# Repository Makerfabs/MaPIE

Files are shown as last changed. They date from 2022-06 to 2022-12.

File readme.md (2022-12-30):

# Makerfabs MaPIE

```c++
/*
Version:		V2.1
Author:			Vincent
Create Date:	2022/6/2
Note:

2022/12/30		V2.1 Edit wiki link
2022/11/23		V2.0 Add MaPIE 0.96 OLED
2022/6/2		V1.0 Create Project
			
*/
```

[toc]

# Makerfabs

[Makerfabs home page](https://www.makerfabs.com/)

[Makerfabs Wiki](https://wiki.makerfabs.com/)

# What is MaPIE 

MaPIE is Makerfabs development board product line based on RP2040.

RP2040 is an MCU developed by Raspberry PI and can support Arduino, MicroPython and C_SDK development.

Compared to the traditional Arduino UNO 328P, it has better performance and more hardware resources. 

## MaPIE List

| Name | Status |
| --- | --- |
| [MaPIE LoRa RP2040](MaPIE_Lora/) | **Already** |
| [MaPIE 0.96 OLED](MaPIE-0.96-OLED/) | **Already** |
| | |

# How To Use

## Complier Option

**If you have any questions，such as how to install the development board, how to download the code, how to install the library. Please refer to :[Makerfabs_FAQ](https://github.com/Makerfabs/Makerfabs_FAQ)**

- Please disconnect from the electrical equipment before burning!
- Do not burn with alternating current!
- Open Arduino IDE
- Open boards Manager, search "RP2040"
- Install board:  Arduino Mbed OS RP2040 Boards(Version 3.1.1)

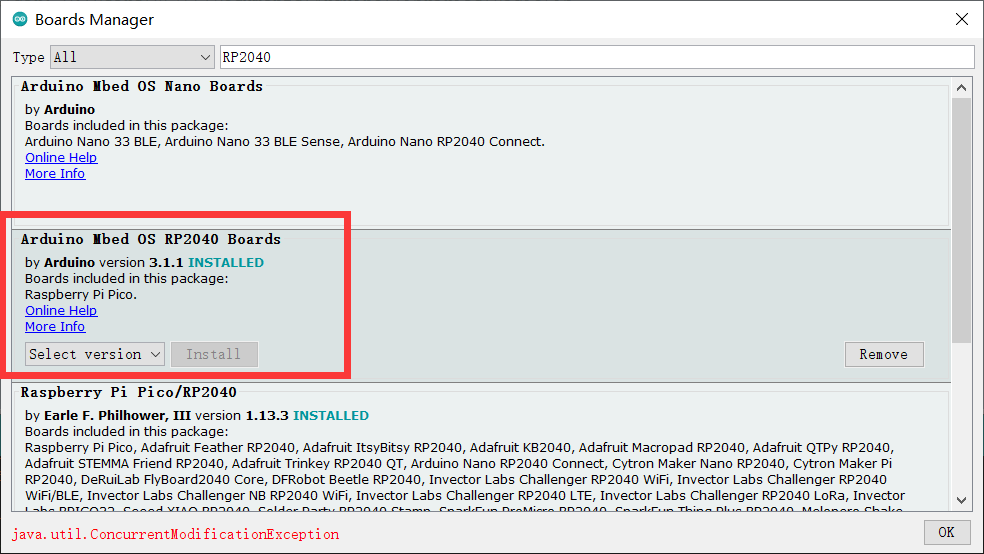
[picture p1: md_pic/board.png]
board


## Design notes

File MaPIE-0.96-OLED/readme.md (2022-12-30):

# MaPIE RP2040 0.96‘‘ OLED

```c++
/*
Version:		V1.0
Author:			Vincent
Create Date:	2022/11/23
Note:
	
*/
```



[toc]

# Makerfabs

[Makerfabs home page](https://www.makerfabs.com/)

[Makerfabs Wiki](https://wiki.makerfabs.com/)

# MaPIE RP2040 0.96‘‘ OLED

## Intruduce

Product Link ：[MaPIE RP2040 0.96" OLED](https://www.makerfabs.com/mapie-rp2040-0-96-inch-oled.html) 

Wiki Link : [MaPIE RP2040 0.96" OLED](https://wiki.makerfabs.com/MaPIE_RP2040_0.96_OLED.html) 

This MaPIE RP2040 OLED is a low-cost, high-performance Pico-like MCU board with flexible digital interfaces. It is based on Raspberry Pi's RP2040 microcontroller chip, as same as that on Raspberry Pi Pico. Users can develop applications based on Raspberry Pi's C/C++ SDK, or the MicroPython/ Arduino.

## Feature

- P2040 microcontroller Dual-core Arm Cortex M0+ processor, flexible clock running up to 133 MHz
- 16MB on-board Flash memory
- USB-C connector
- 0.96" 128*64 OLED
- Lithium battery connector/ charge
- Same pins breakout as Pico: 26 x multi-function GPIO pins; 2 x SPI, 2 x I2C, 2 x UART, 3 x 12-bit ADC, 16 x controllable PWM channels

### Front:

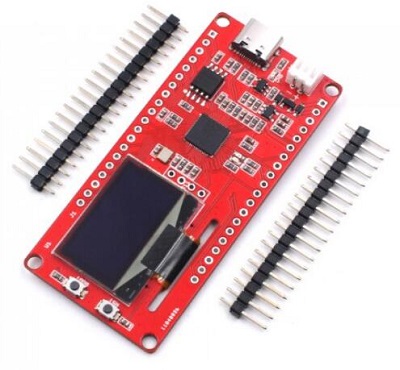
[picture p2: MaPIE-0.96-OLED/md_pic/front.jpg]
front


### Back:

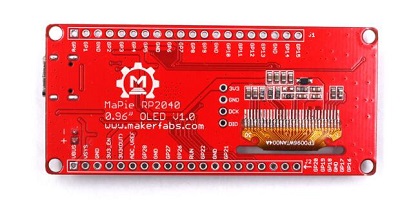
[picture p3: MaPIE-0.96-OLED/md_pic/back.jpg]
back


# Arduino

## Compiler Options

**If you have any questions，such as how to install the development board, how to download the code, how to install the library. Please refer to :[Makerfabs_FAQ](https://github.com/Makerfabs/Makerfabs_FAQ)**

- Install board : Arduino Mbed OS RP2040 Boards
- Install library : Adafruit_GFX library.
- Install library : Adafruit_SSD1306 library.

rp2040

Modify pins_Arduino.h

```c++
//variants\RASPBERRY_PI_PICO\pins_arduino.h

// Wire
// #define PIN_WIRE_SDA        (4u)
// #define PIN_WIRE_SCL        (5u)

// Change By Vincent
#define PIN_WIRE_SDA        (6u)
#define PIN_WIRE_SCL        (7u)
```

**First time upload need hold boot button when restart.**

# MicroPython

## Burn Fireware

Download MicroPython from the Raspberry PI Pico's official tutorial:

[https://www.raspberrypi.com/products/raspberry-pi-pico/](https://www.raspberrypi.com/products/raspberry-pi-pico/)

## Upload Code

Connect MaPie to PC.

Use Thonny IDE, upload all file to MaPie.

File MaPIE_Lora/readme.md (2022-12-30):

# MaPIE LoRa RP2040

```c++
/*
Version:		V1.1
Author:			Vincent
Create Date:	2022/6/2
Note:
				V1.0 Create Project
				V1.1 Add hardware file
			
*/
```

[toc]

# Makerfabs

[Makerfabs home page](https://www.makerfabs.com/)

[Makerfabs Wiki](https://wiki.makerfabs.com/)

# MaPIE LoRa RP2040

## Introduce

Product Link ：[MaPIE LoRa RP2040](https://www.makerfabs.com/mapie-lora-rp2040.html) 

Wiki Link : [MaPIE LoRa RP2040](https://wiki.makerfabs.com/MaPIE_LoRa_RP2040.html) 

Makerfabs MaPIE Lora is based on Raspberry Pi PICO RP2040 controller, with integration of flash and Lora RFM98W, to make it a good platform for RP2040 development of Lora applications.

## Feature

- Raspberry RP2040 MCU
- Lora frequency: 433M/ 868M/ 915M
- Support Micro SD Card
- On board Flash: 16MB
- Power: USB Type-C; battery; On board charger

### Front:

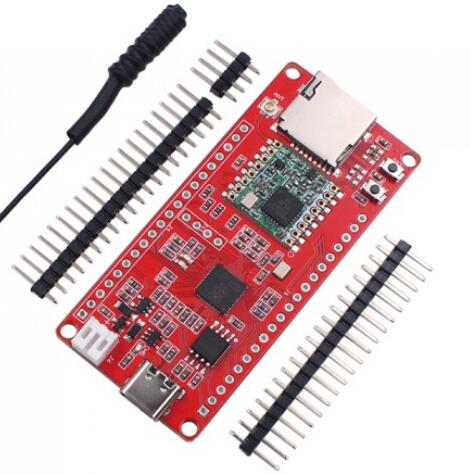
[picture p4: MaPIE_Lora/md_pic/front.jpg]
front


### Back:

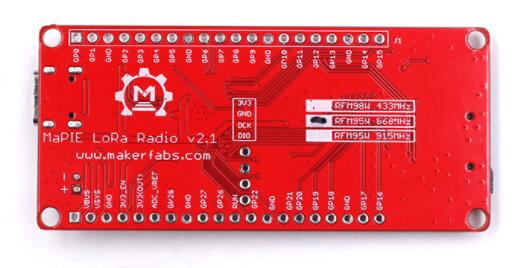
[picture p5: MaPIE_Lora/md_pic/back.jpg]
back


# How To Use

## Complier Option

**If you have any questions，such as how to install the development board, how to download the code, how to install the library. Please refer to :[Makerfabs_FAQ](https://github.com/Makerfabs/Makerfabs_FAQ)**

- Please disconnect from the electrical equipment before burning!
- Do not burn with alternating current!
- Install library: RadioLib and other libs in Arduino IDE
- Upload codes, select "Arduino Mbed OS RP2040 Boards" and "Raspberry Pi Pico"

MaPIE Lora Radio use this Lora library: [RadioLib](https://github.com/jgromes/RadioLib)

**It is recommended to install from Arduino Library Manager and select the library version 4.6.0. RadioLib libraries after 5.0 need to add "RADIOLIB_" before some macro definitions.**

The current firmware is developed in RadioLib 4.6.0.

## Firmware

### MaPIE_LORA_V1.0 

The main function is to verify SD card and provide simple Lora reception.

Some SD cards tested are incompatible or have a low success rate, such as the Kingston 8G.

**We provide a compiled UF2 file that you can upload directly. Hold down BOOT and press RST. The RP2040 will convert to a USB drive and send the UF2 file to the USB drive for uploading.**

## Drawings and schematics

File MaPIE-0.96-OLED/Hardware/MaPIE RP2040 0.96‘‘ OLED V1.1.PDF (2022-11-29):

## I2C SPI3

0

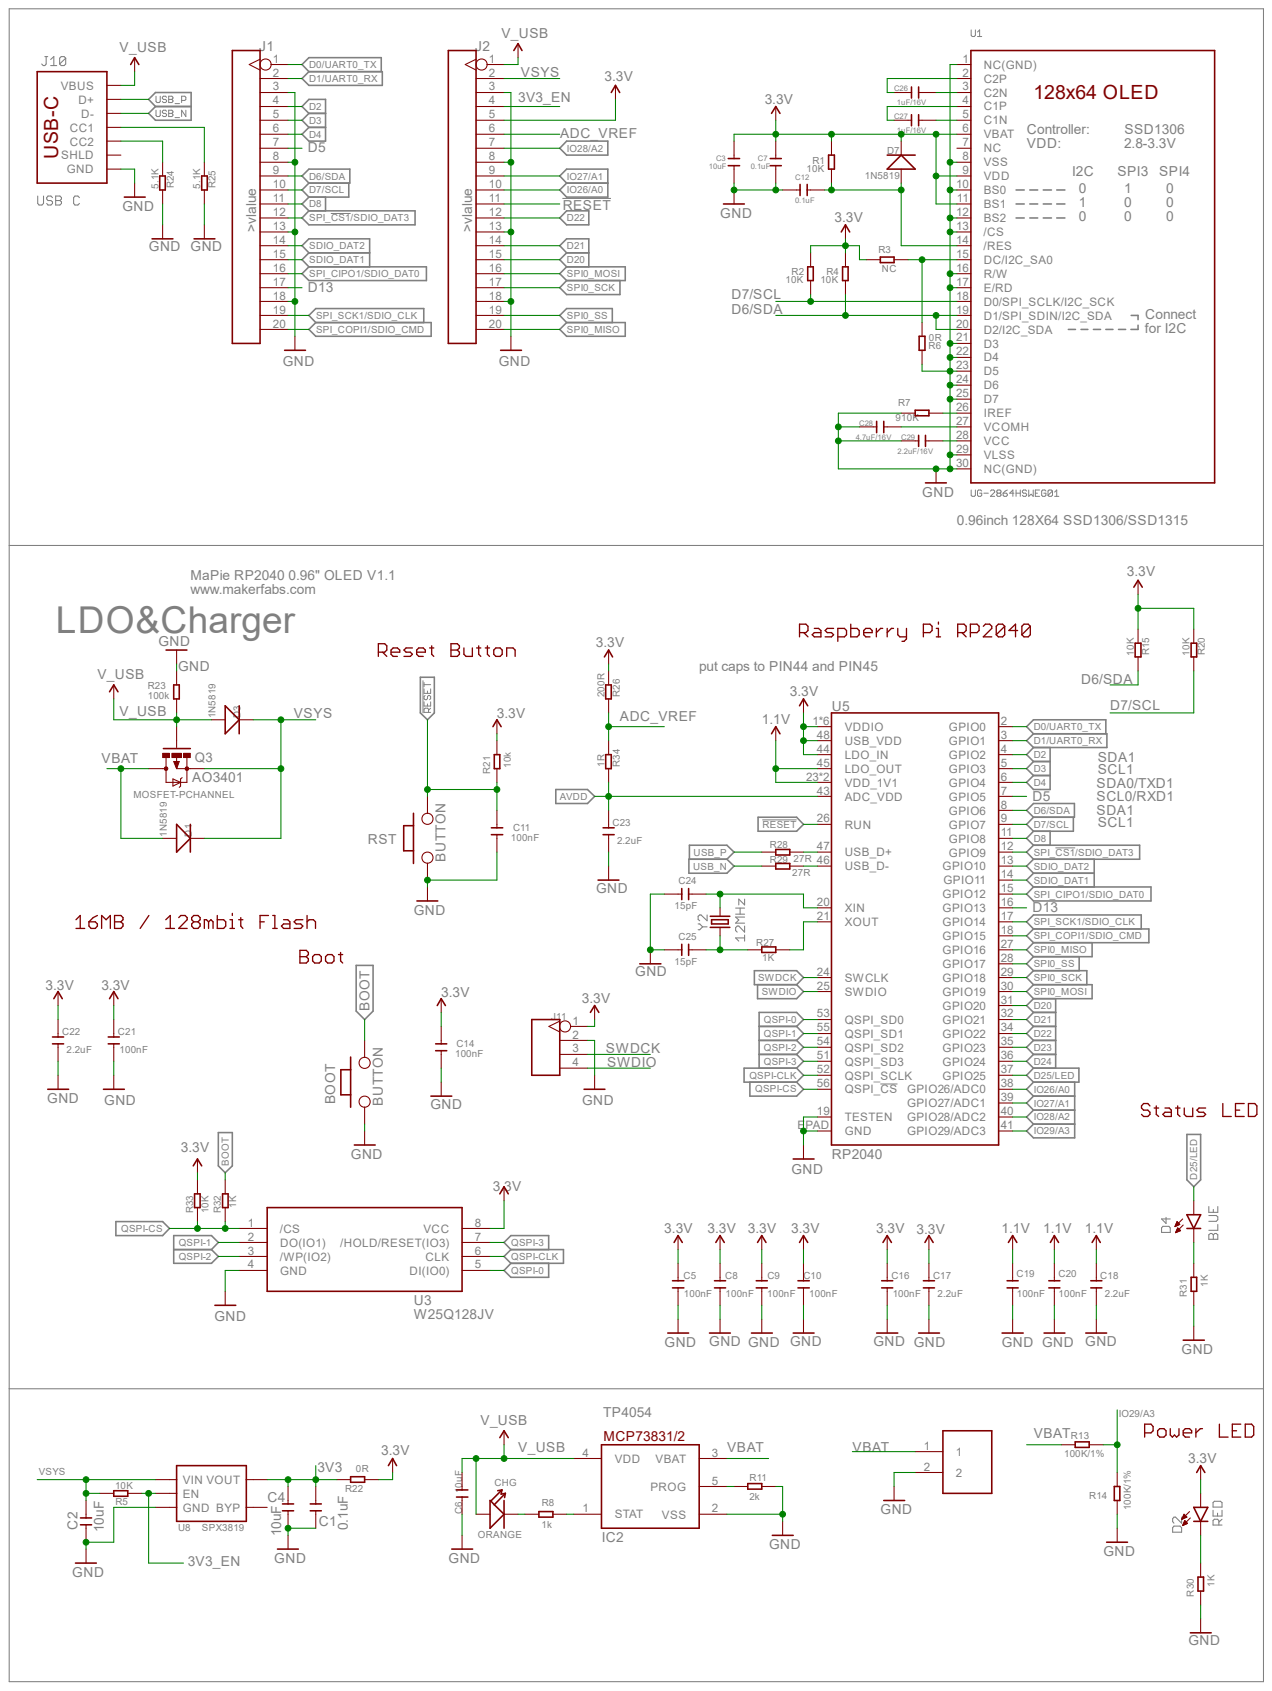
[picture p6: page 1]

13 | 13
14 | 14

17 | 17
18 | 18

put caps to PIN44 and PIN45

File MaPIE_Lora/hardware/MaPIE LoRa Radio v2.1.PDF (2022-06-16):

GNDBUTTON | BUTTON
GND | >vlalue | >vlalue 10uF

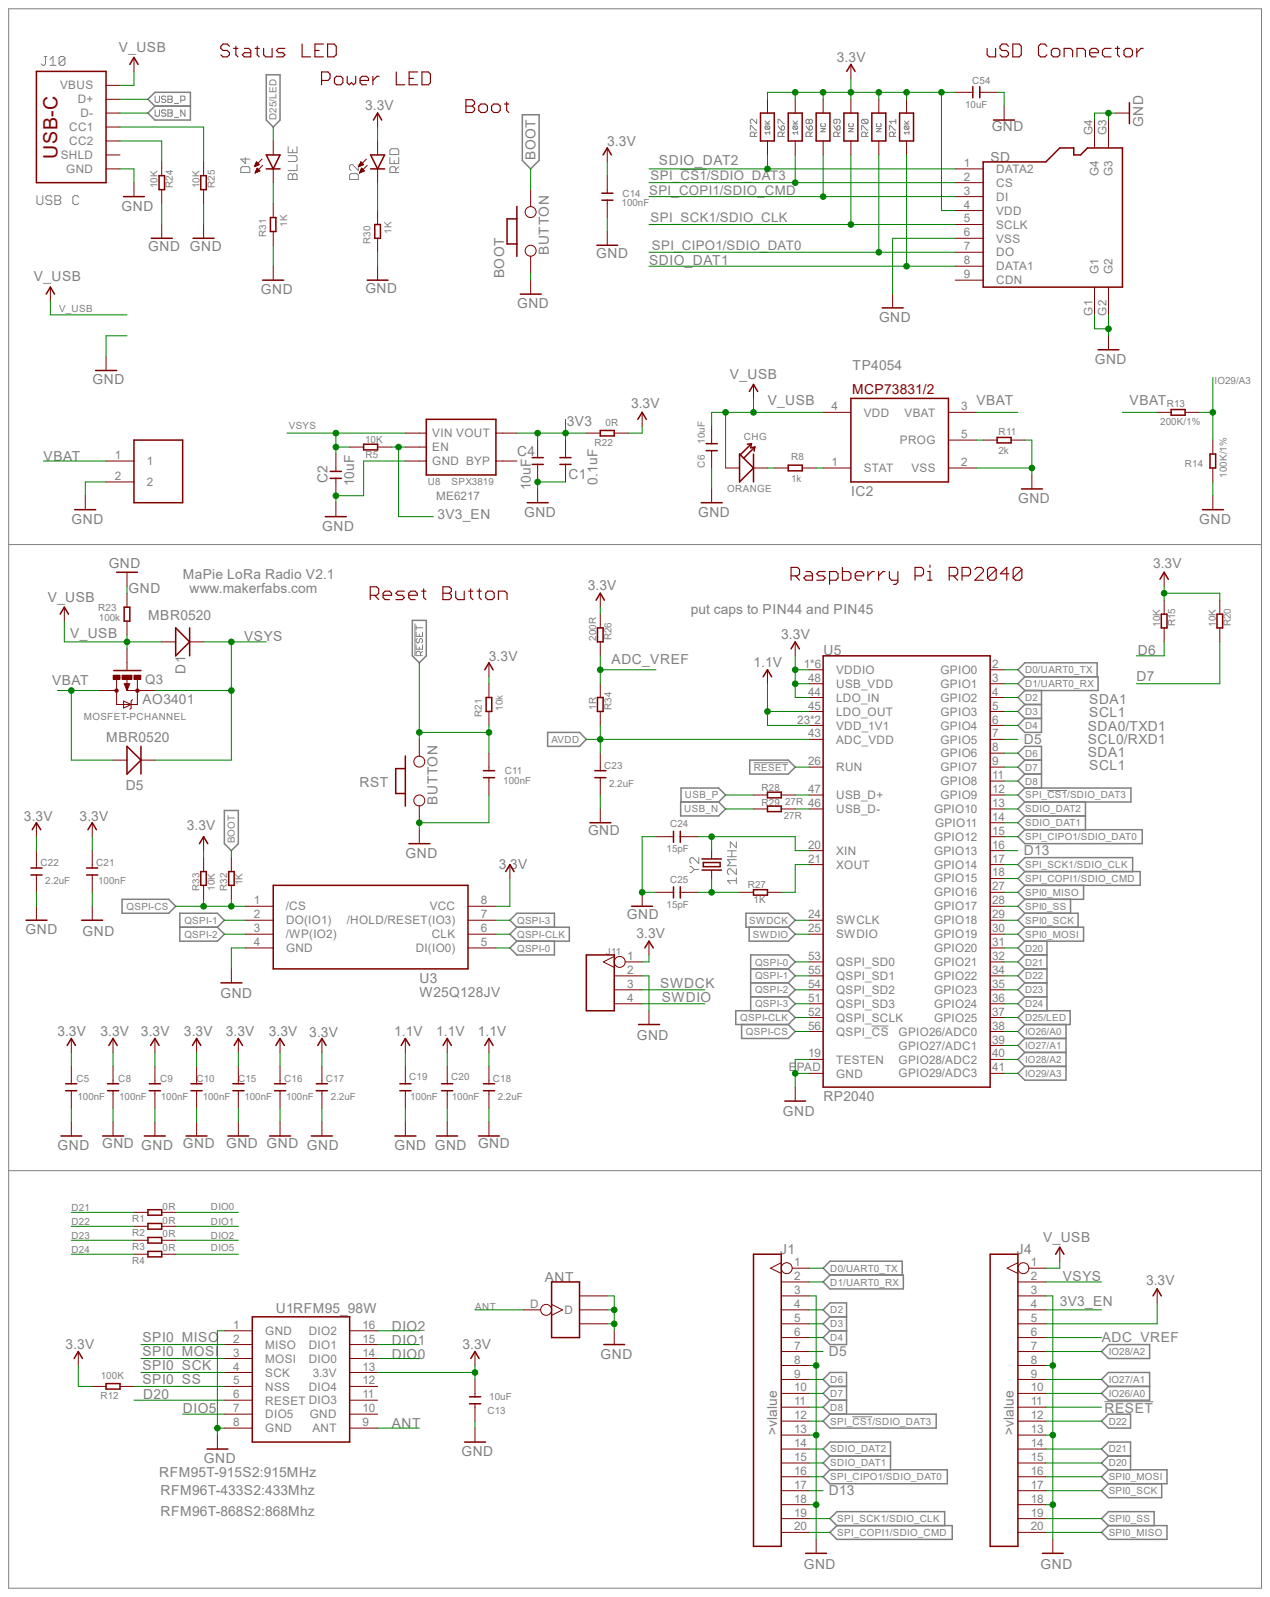
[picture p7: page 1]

VDD 4

VSS 6
DO 7

put caps to PIN44 and PIN45

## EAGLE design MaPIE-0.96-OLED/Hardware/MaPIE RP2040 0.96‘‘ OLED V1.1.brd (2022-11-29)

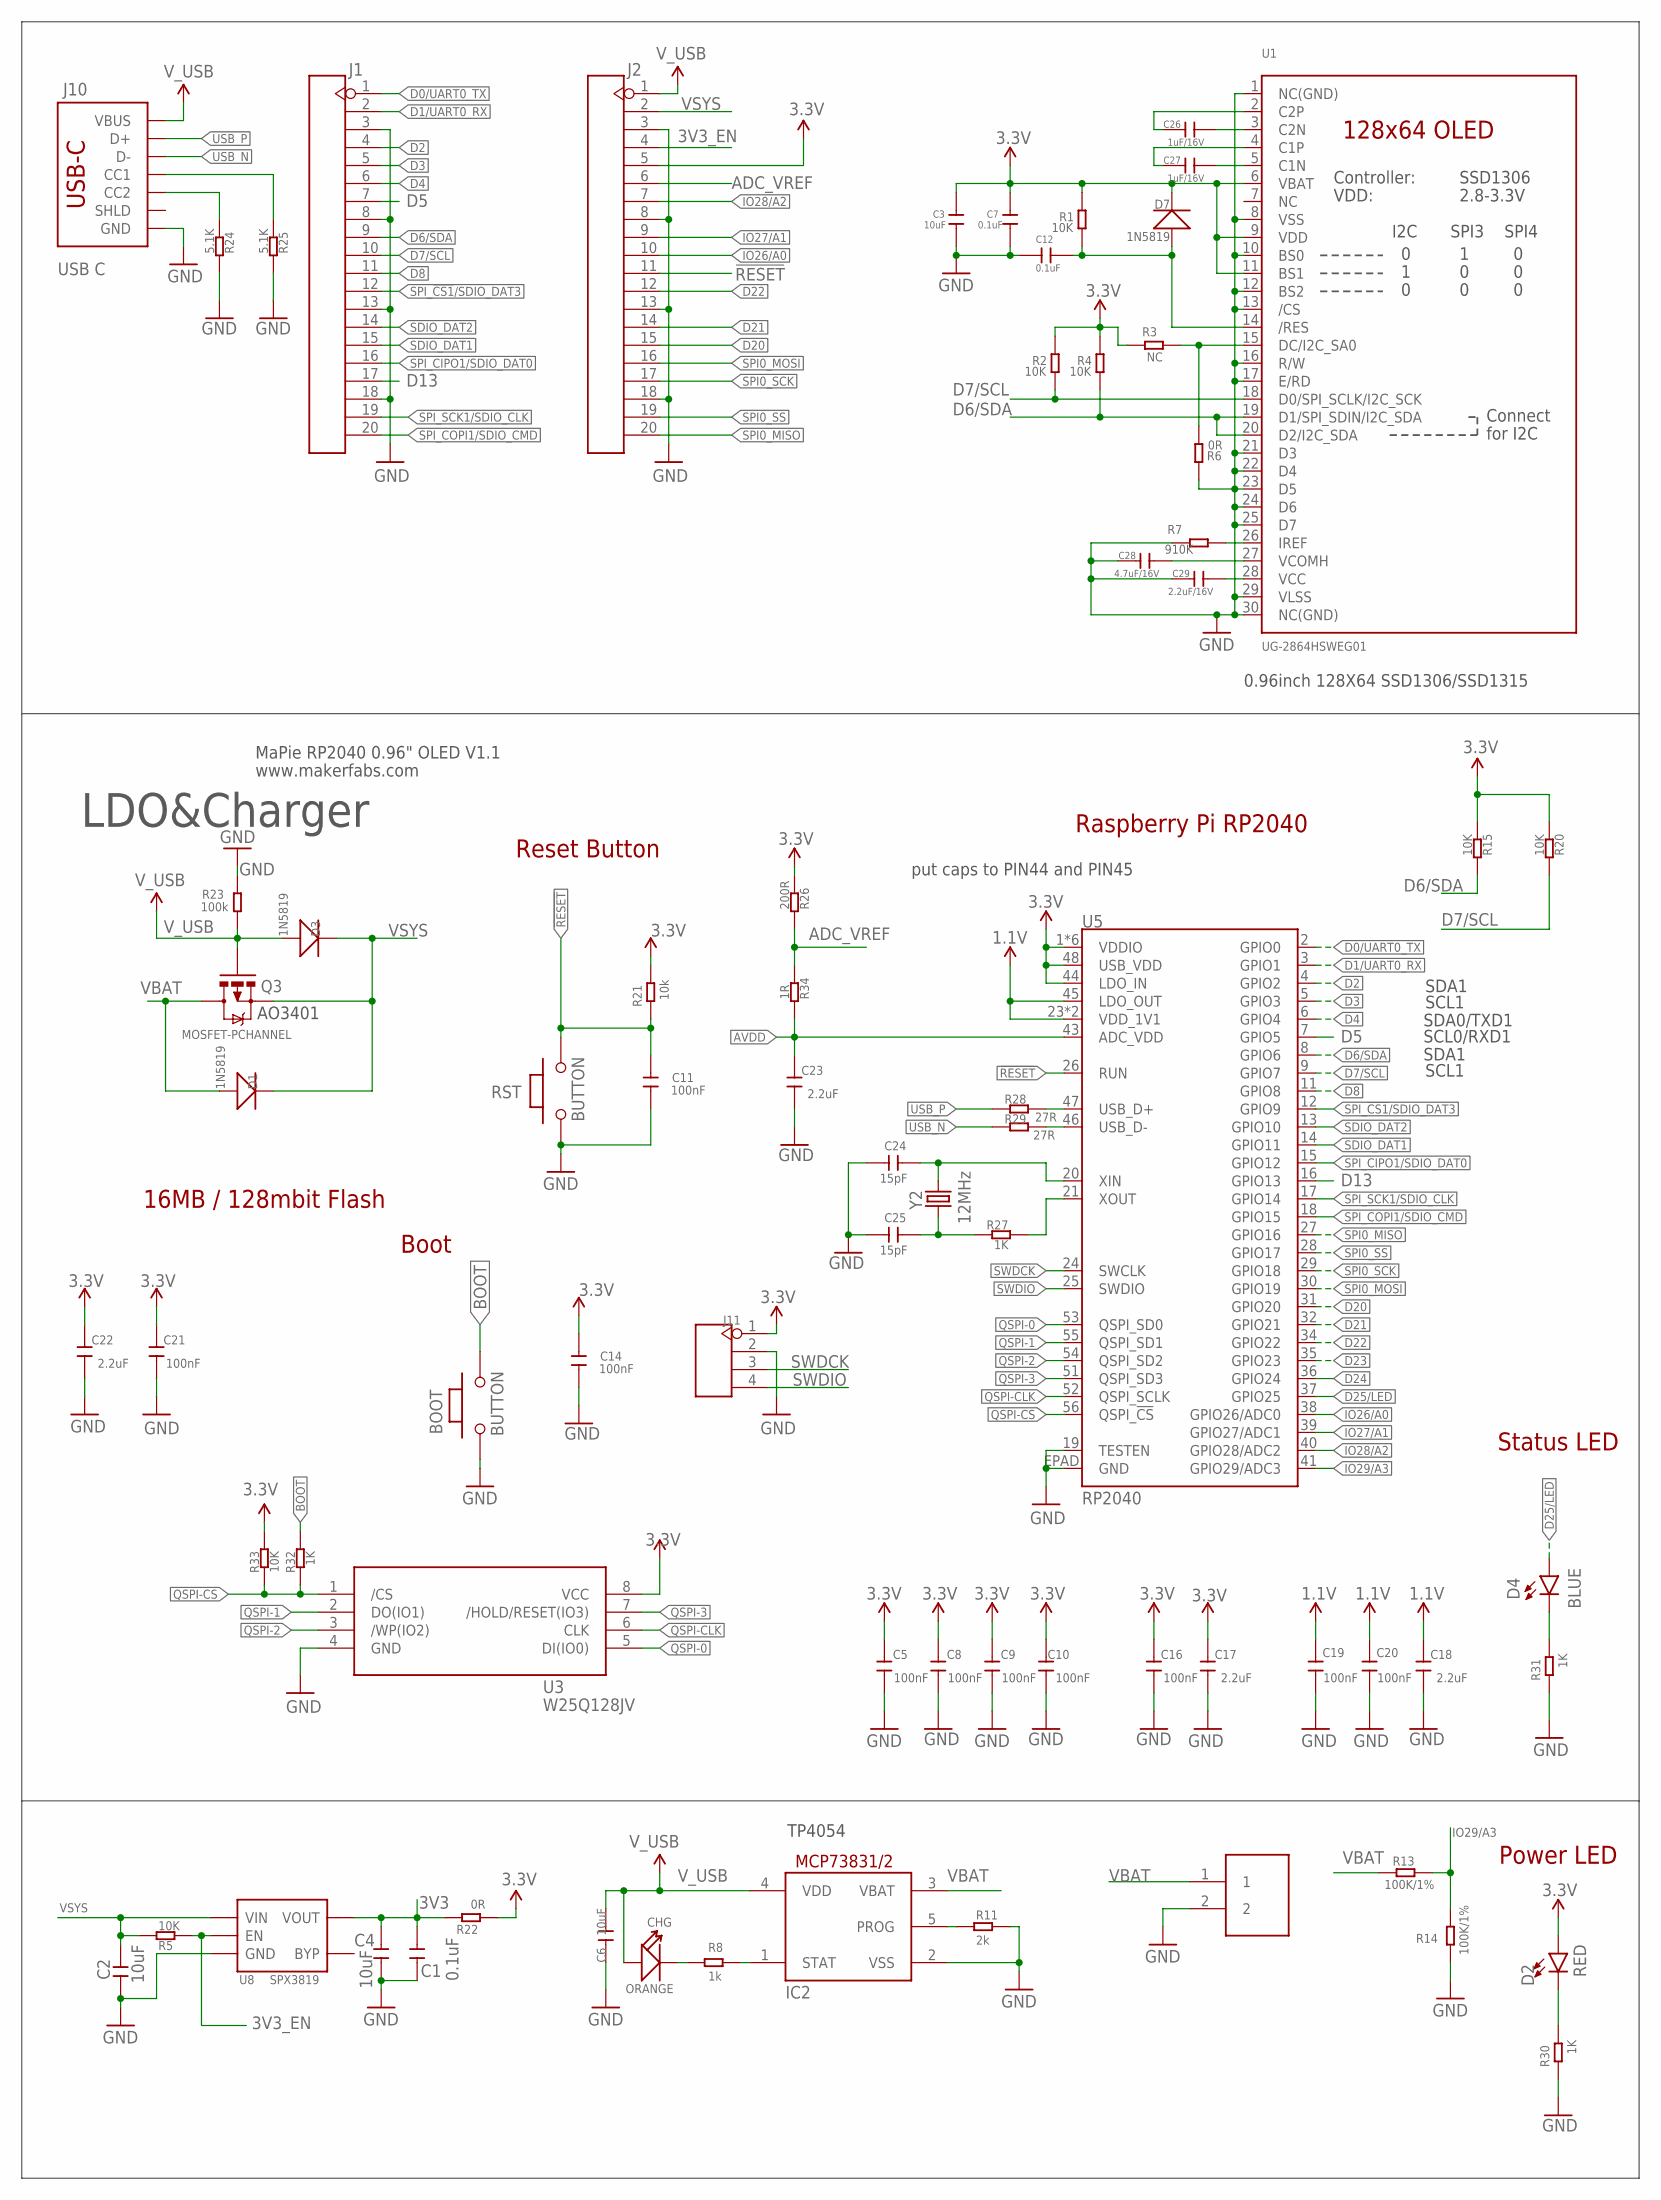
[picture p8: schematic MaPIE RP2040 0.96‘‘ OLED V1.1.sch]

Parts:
BAT: PH2.0-2P-90-DIP
BOOT: BUTTON; 157SW
C1, C7, C12: 0.1uF; C0603
C2, C3, C4, C6: 10uF; C0603
C5, C8, C9, C10, C11, C14, C16, C19, C20, C21: 100nF; C0603
C17, C18, C22, C23: 2.2uF; C0603
C24, C25: 15pF; C0603
C26, C27: 1uF/16V; C0603
C28: 4.7uF/16V; C0603
C29: 2.2uF/16V; C0603
CHG: ORANGE; D0603
D1, D3, D7: 1N5819; SOD323
D2: RED; LED-0603
D4: BLUE; LED-0603
IC2: MCP73831/OT; SOT23-5L
J1, J2: HEADER-20P-2.54; 20P-2.54
J10: USB C; USB-C-16P-4LAYER-ISOLATED
J11: HEADER-4P-60/35MILROUND; 4P-65/35ROUND
Q3: MOSFET-PCHANNEL; SOT23-3
R1, R2, R4, R5, R15, R20, R33: 10K; 0603
R3: NC; 0603
R6, R22: 0R; 0603
R7: 910K; 0603
R8: 1k; 0603
R11: 2k; 0603
R13, R14: 100K/1%; 0603
R21: 10k; 0603
R23: 100k; 0603
R24, R25: 5.1K; 0603
R26: 200R; 0603
R27, R30, R31, R32: 1K; 0603
R28, R29: 27R; 0603
R34: 1R; 0603
RST: BUTTON; 157SW
U1: UG-2864HSWEG01; UG-2864HSWEG01_0.96IN_WRAPAROUND
U3: W25Q128JV; SOIC-8-208MIL
U5: RP2040; QFN-56
U8: SPX3819; SOT23-5
Y2: 12MHz; CRYSTAL-SMD-2X2.5MM

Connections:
1.1V: C18.2, C19.2, C20.2, U5.23 (VDD_1V1), U5.45 (LDO_OUT), U5.50 (VDD_1V1)
3.3V: C3.1, C5.2, C7.1, C8.2, C9.2, C10.2, C14.2, C16.2, C17.2, C21.2, C22.2, D2.A, D7.-, J2.5, J11.1, R1.2, R2.2, R3.2, R4.2, R15.2, R20.2, R21.1, R22.1, R26.2, R33.1, U1.6 (VBAT), U1.9 (VDD), U1.11 (BS1), U3.8 (VCC), U5.1 (VDDIO), U5.10 (VDDIO), U5.22 (VDDIO), U5.33 (VDDIO), U5.42 (VDDIO), U5.44 (LDO_IN), U5.48 (USB_VDD), U5.49 (VDDIO)
3V3: C1.2, C4.2, R22.2, U8.5 (VOUT)
3V3_EN: J2.4, R5.2, U8.3 (EN)
!RESET!: C11.2, J2.11, R21.2, RST.2, U5.26 (RUN)
ADC_VREF: J2.6, R26.1, R34.2
AVDD: C23.2, R34.1, U5.43 (ADC_VDD)
BOOT: BOOT.2, R32.1
D0/UART0_TX: J1.1, U5.2 (GPIO0)
D1/UART0_RX: J1.2, U5.3 (GPIO1)
D2: J1.4, U5.4 (GPIO2)
D3: J1.5, U5.5 (GPIO3)
D4: J1.6, U5.6 (GPIO4)
D5: J1.7, U5.7 (GPIO5)
D6/SDA: J1.9, R4.1, R15.1, U1.19 (D1/SPI_SDIN/I2C_SDA), U1.20 (D2/I2C_SDA), U5.8 (GPIO6)
D7/SCL: J1.10, R2.1, R20.1, U1.18 (D0/SPI_SCLK/I2C_SCK), U5.9 (GPIO7)
D8: J1.11, U5.11 (GPIO8)
D13: J1.17, U5.16 (GPIO13)
D20: J2.15, U5.31 (GPIO20)
D21: J2.14, U5.32 (GPIO21)
D22: J2.12, U5.34 (GPIO22)
D23: U5.35 (GPIO23)
D24: U5.36 (GPIO24)
D25/LED: D4.A, U5.37 (GPIO25)
GND: BAT.2, BOOT.1, C1.1, C2.1, C3.2, C4.1, C5.1, C6.1, C7.2, C8.1, C9.1, C10.1, C11.1, C12.1, C14.1, C16.1, C17.1, C18.1, C19.1, C20.1, C21.1, C22.1, C23.1, C24.2, C25.2, C28.1, C29.1, IC2.2 (VSS), J1.3, J1.8, J1.13, J1.18, J2.3, J2.8, J2.13, J2.18, J10.GND, J10.GND2 (GND), J11.2, R6.2, R7.2, R11.2, R14.1, R23.2, R24.1, R25.1, R30.2, R31.2, RST.1, U1.1 (NC(GND)), U1.8 (VSS), U1.10 (BS0), U1.12 (BS2), U1.13 (/CS), U1.16 (R/W), U1.17 (E/RD), U1.21 (D3), U1.22 (D4), U1.23 (D5), U1.24 (D6), U1.25 (D7), U1.29 (VLSS), U1.30 (NC(GND)), U3.4 (GND), U5.19 (TESTEN), U5.EPAD (GND), U8.2 (GND)
IO26/A0: J2.10, U5.38 (GPIO26/ADC0)
IO27/A1: J2.9, U5.39 (GPIO27/ADC1)
IO28/A2: J2.7, U5.40 (GPIO28/ADC2)
IO29/A3: R13.1, R14.2, U5.41 (GPIO29/ADC3)
unnamed: C24.1, U5.20 (XIN), Y2.P3 (2)
unnamed: D4.C, R31.1
unnamed: R3.1, R6.1, U1.15 (DC/I2C_SA0)
unnamed: R27.1, U5.21 (XOUT)
unnamed: C28.2, U1.27 (VCOMH)
unnamed: C25.1, R27.2, Y2.P1 (1)
unnamed: D2.C, R30.1
unnamed: C29.2, U1.28 (VCC)
unnamed: R7.1, U1.26 (IREF)
unnamed: C26.2, U1.3 (C2N)
unnamed: J10.A5 (CC1), R25.2
unnamed: J10.B5 (CC2), R24.2
unnamed: C26.1, U1.2 (C2P)
unnamed: C27.1, U1.4 (C1P)
unnamed: C27.2, U1.5 (C1N)
unnamed: C12.2, D7.+, R1.1, U1.14 (/RES)
unnamed: CHG.-, R8.1
unnamed: IC2.1 (STAT), R8.2
unnamed: IC2.5 (PROG), R11.1
QSPI-0: U3.5 (DI(IO0)), U5.53 (QSPI_SD0)
QSPI-1: U3.2 (DO(IO1)), U5.55 (QSPI_SD1)
QSPI-2: U3.3 (/WP(IO2)), U5.54 (QSPI_SD2)
QSPI-3: U3.7 (/HOLD/RESET(IO3)), U5.51 (QSPI_SD3)
QSPI-CLK: U3.6 (CLK), U5.52 (QSPI_SCLK)
QSPI-CS: R32.2, R33.2, U3.1 (/CS), U5.56 (QSPI_!CS!)
SDIO_DAT1: J1.15, U5.14 (GPIO11)
SDIO_DAT2: J1.14, U5.13 (GPIO10)
SPI0_MISO: J2.20, U5.27 (GPIO16)
SPI0_MOSI: J2.16, U5.30 (GPIO19)
SPI0_SCK: J2.17, U5.29 (GPIO18)
SPI0_SS: J2.19, U5.28 (GPIO17)
SPI_!CS1!/SDIO_DAT3: J1.12, U5.12 (GPIO9)
SPI_CIPO1/SDIO_DAT0: J1.16, U5.15 (GPIO12)
SPI_COPI1/SDIO_CMD: J1.20, U5.18 (GPIO15)
SPI_SCK1/SDIO_CLK: J1.19, U5.17 (GPIO14)
SWDCK: J11.3, U5.24 (SWCLK)
SWDIO: J11.4, U5.25 (SWDIO)
USB_F_N: R29.1, U5.46 (USB_D-)
USB_F_P: R28.1, U5.47 (USB_D+)
USB_N: J10.A7 (D-), J10.B7 (D-), R29.2
USB_P: J10.A6 (D+), J10.B6 (D+), R28.2
VBAT: BAT.1, D1.+, IC2.3 (VBAT), Q3.3 (D), R13.2
VSYS: C2.2, D1.-, D3.-, J2.2, Q3.2 (S), R5.1, U8.1 (VIN)
V_USB: C6.2, CHG.+, D3.+, IC2.4 (VDD), J2.1, J10.VBUS1 (VBUS), J10.VBUS2 (VBUS), Q3.1 (G), R23.1

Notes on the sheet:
MaPie RP2040 0.96" OLED V1.1
www.makerfabs.com
TP4054
16MB / 128mbit Flash
Raspberry Pi RP2040
Reset Button
Status LED
Boot
Power LED
put caps to PIN44 and PIN45
SDA0/TXD1
SCL0/RXD1
SDA1
SCL1
LDO&Charger
AO3401
0.96inch 128X64 SSD1306/SSD1315

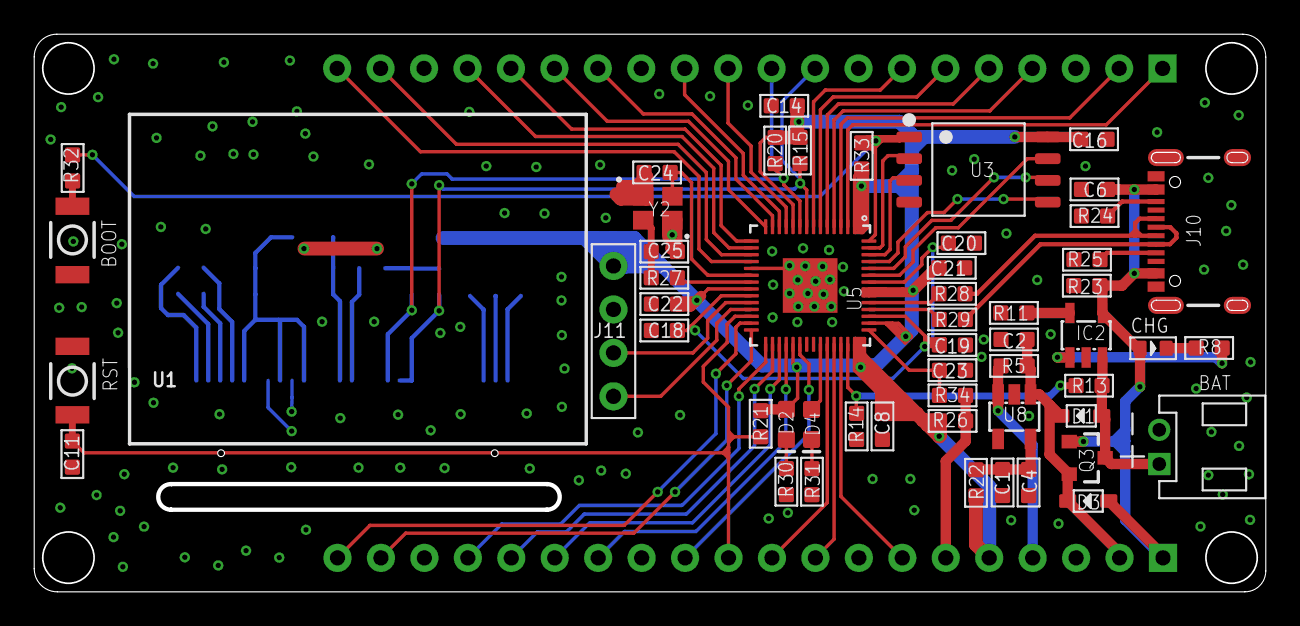
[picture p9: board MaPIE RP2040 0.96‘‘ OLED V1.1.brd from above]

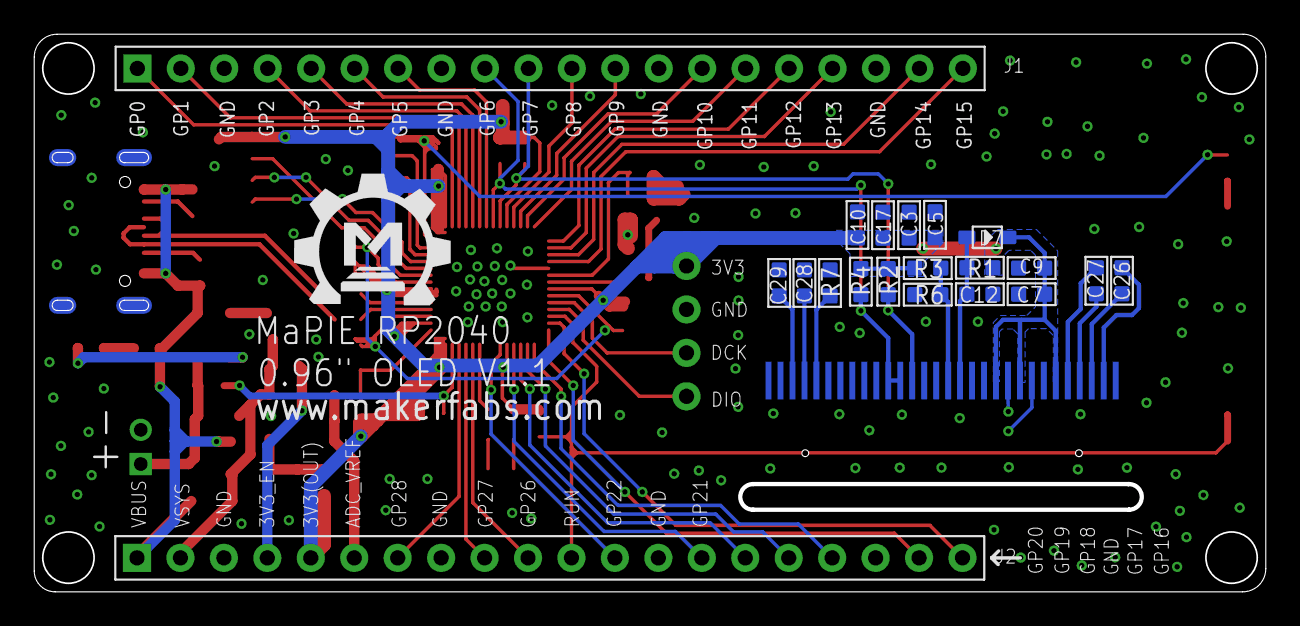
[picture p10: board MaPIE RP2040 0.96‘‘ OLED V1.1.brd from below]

Board: 2 copper layers, 72.0 x 32.6 mm, 75 parts (21 on the bottom side), 71 nets.

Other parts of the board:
U$1: MAKERFABS_0.3

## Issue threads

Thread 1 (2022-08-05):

Mapie Lora 433Mhz Board not showing as USB Drive.

guneshgg, 2022-08-05:
"We provide a compiled UF2 file that you can upload directly. Hold down BOOT and press RST. The RP2040 will convert to a USB drive and send the UF2 file to the USB drive for uploading."

Referring to the instruction above, 2 scenarios were conducted. 1) powered via the LiPo port and 2) via the 3V + GND pins in the middle.

Board: Mapie Lora Radio v2.2

Observation:

with the power from the 3v pins in the middle:
1. The board lights up with the Red LED
2. Hold down BOOT and press RST - Also Tried Boot Button Alone like the same way as the Pico.
3. USBC cables plugged in both device and PC (This is done before and after step 3)
4. No port detected or Drive detected in OSX (M1 Mac)

with the power from the LiPo pins:
1. The board lights up with the Red LED
2. Hold down BOOT and press RST
3. USBC cables plugged in both device and PC (This is done before and after step 3)
4. No port detected or Drive detected in OSX (M1 Mac)
5. Sometimes the Blue LED will light up.
6. On starting the entire process with the Micro SD card in it, on removing the SD Card, the Blue LED blinks, 3 times slow, 3 times fast in a loop.

There is almost no documentation available, no reference boards to refer too as well.

I would like to take this 1 step at a time, just to detect the PORT or the USB Drive.

Please assist.

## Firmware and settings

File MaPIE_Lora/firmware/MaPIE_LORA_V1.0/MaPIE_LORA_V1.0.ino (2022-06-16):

/*

使用同一个硬件SPI带LORA和SD卡

// SPI
#define PIN_SPI_MISO  (16u)
#define PIN_SPI_MOSI  (19u)
#define PIN_SPI_SCK   (18u)
#define PIN_SPI_SS    (17u)

Arduino官方只声明了一个SPI库
公用同一个SPI时必须先调用RP2040_SD的库，会初始化SPI
然后再用Lora库，并且不初始化SPI，不然会报错

然后必须手动控制CS开关，尚不清楚是哪个库不能这样用。

库版本
Using library SPI in folder: C:\Users\86156\AppData\Local\Arduino15\packages\arduino\hardware\mbed_rp2040\3.1.1\libraries\SPI (legacy)
Using library RP2040_SD at version 1.0.1 in folder: C:\Users\86156\Documents\Arduino\libraries\RP2040_SD
Using library RadioLib at version 4.6.0 in folder: C:\Users\86156\Documents\Arduino\libraries\RadioLib


*/

#include <SPI.h>
#include <RP2040_SD.h>
#include <RadioLib.h>

#define LORA_CS 17
#define SD_CS 9

// SPI
#define PIN_SPI_MISO (16u)
#define PIN_SPI_MOSI (19u)
#define PIN_SPI_SCK (18u)
#define PIN_SPI_SS (17u)

#define LORA_DIO0 21
#define LORA_DIO1 22
#define LORA_DIO2 23
#define LORA_DIO5 24
#define LORA_RST 20

#define FREQUENCY 915.0
#define BANDWIDTH 125.0
#define SPREADING_FACTOR 9
#define CODING_RATE 7
#define OUTPUT_POWER 10
#define PREAMBLE_LEN 8
#define GAIN 0

// SX1276 radio = new Module(LORA_CS, LORA_DIO0, LORA_RST, LORA_DIO1);
SX1276 radio = new Module(LORA_CS, LORA_DIO0, LORA_RST, LORA_DIO1, SPI, SPISettings());
File root;
long unsigned int runtime = 0;

#define LORA_CS_OFF digitalWrite(LORA_CS, HIGH)
#define LORA_CS_ON digitalWrite(LORA_CS, LOW)
#define SD_CS_OFF digitalWrite(SD_CS, HIGH)
#define SD_CS_ON digitalWrite(SD_CS, LOW)

void setup(void)
{
    Serial.begin(115200);

    pinMode(LORA_CS, OUTPUT);
    pinMode(SD_CS, OUTPUT);

    pinMode(PIN_SPI_MISO, INPUT);
    pinMode(PIN_SPI_MOSI, OUTPUT);
    pinMode(PIN_SPI_SCK, OUTPUT);

    LORA_CS_OFF;
    SD_CS_OFF;
    // SPI.end();

    delay(3000);
    Serial.println(F("Hello! Lora Test"));

    SD_CS_ON;

    while (1)
    {
        if (!SD.begin(SD_CS))
        {
            SD.end();
            Serial.println("SD init failed!");
            delay(1000);
            continue;
        }
        else
        {
            Serial.println("SD init done.");
            break;
        }
    }

    sd_test();
    SD_CS_OFF;

    LORA_CS_ON;
    int state = radio.begin(FREQUENCY, BANDWIDTH, SPREADING_FACTOR, CODING_RATE, SX127X_SYNC_WORD, OUTPUT_POWER, PREAMBLE_LEN, GAIN);

    if (state == ERR_NONE)
    {
        Serial.println(F("success!"));
    }
    else
    {
        Serial.print(F("failed, code "));
        Serial.println(state);
        while (true)
            ;
    }

    runtime = millis();
}

void loop()
{
    lora_node_general();
    if ((millis() - runtime) > 10000)
    {
        LORA_CS_OFF;
        SD_CS_ON;

        sd_test();
        runtime = millis();

        SD_CS_OFF;
        LORA_CS_ON;
    }
}

void lora_node_general()
{
    Serial.print(F("[SX1278] Waiting for incoming transmission ... "));

    String str;
    int state = radio.receive(str);

    if (state == ERR_NONE)
    {
        // packet was successfully received
        Serial.println(F("success!"));

        // print the data of the packet
        Serial.print(F("[SX1278] Data:\t\t\t"));
        Serial.println(str);

        // print the RSSI (Received Signal Strength Indicator)
        // of the last received packet
        Serial.print(F("[SX1278] RSSI:\t\t\t"));
        Serial.print(radio.getRSSI());
        Serial.println(F(" dBm"));

        // print the SNR (Signal-to-Noise Ratio)
        // of the last received packet
        Serial.print(F("[SX1278] SNR:\t\t\t"));
        Serial.print(radio.getSNR());
        Serial.println(F(" dB"));

        // print frequency error
        // of the last received packet
        Serial.print(F("[SX1278] Frequency error:\t"));
        Serial.print(radio.getFrequencyError());
        Serial.println(F(" Hz"));
    }
    else if (state == ERR_RX_TIMEOUT)
    {
        // timeout occurred while waiting for a packet
        Serial.println(F("timeout!"));
    }
    else if (state == ERR_CRC_MISMATCH)
    {
        // packet was received, but is malformed
        Serial.println(F("CRC error!"));
    }
    else
    {
        // some other error occurred
        Serial.print(F("failed, code "));
        Serial.println(state);
    }
}

void sd_test()
{
    String fileName = "datalog.txt";
    String fileName1 = "newdata.txt";

    root = SD.open("/");

    printDirectory(root, 0);

    Serial.println("Print Directory done!");

    File myWFile = SD.open(fileName, FILE_WRITE);

    if (myWFile)
    {
        char writeData[] = "Testing RP2040 SD";

        myWFile.write((uint8_t *)&writeData, sizeof(writeData));

        Serial.print("writeData = ");
        Serial.println(writeData);

        myWFile.close();
    }
    else
    {
        Serial.print("Error open for writing ");
        Serial.println(fileName);
    }

    myWFile = SD.open(fileName1, FILE_WRITE);

    if (myWFile)
    {
        char writeData[] = "Testing RP2040 SD";

        // myWFile.seek(0, (SeekMode) SEEK_END);

        myWFile.write((uint8_t *)&writeData, sizeof(writeData));

        myWFile.close();
    }
    else
    {
        Serial.print("Error open for writing ");
        Serial.println(fileName1);
    }

    // OK here to read file
    File myRFile = SD.open(fileName, FILE_READ);

    if (myRFile)
    {
        char readData[64] = "\0";

        // myWFile.seek(0, (SeekMode) SEEK_END);

        myRFile.read((uint8_t *)&readData, sizeof(readData) - 1);

        myRFile.close();

        Serial.print("readData = ");
        Serial.println(readData);
    }
    else
    {
        Serial.print("Error open for reading ");
        Serial.println(fileName);
    }

    root = SD.open("/");

    printDirectory(root, 0);

    Serial.println("Print Directory done!");
}

void printDirectory(File dir, int numTabs)
{
    while (true)
    {
        File entry = dir.openNextFile();

        if (!entry)
        {
            // no more files
            break;
        }

        for (uint8_t i = 0; i < numTabs; i++)
        {
            Serial.print('\t');
        }

        Serial.print(entry.name());

        if (entry.isDirectory())
        {
            Serial.println("/");
            printDirectory(entry, numTabs + 1);
        }
        else
        {
            // files have sizes, directories do not
            Serial.print("\t\t");
            Serial.println(entry.size(), DEC);
        }

        entry.close();
    }
}

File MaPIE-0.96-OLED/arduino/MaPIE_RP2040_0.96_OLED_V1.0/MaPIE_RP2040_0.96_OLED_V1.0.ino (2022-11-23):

#include <Wire.h>
#include <Adafruit_GFX.h>
#include <Adafruit_SSD1306.h>
#include <arduino.h>

#define I2C_SDA_PIN 6
#define I2C_SCL_PIN 7

#define SCREEN_WIDTH 128 // OLED display width, in pixels
#define SCREEN_HEIGHT 64 // OLED display height, in pixels

#define OLED_RESET -1 // Reset pin # (or -1 if sharing Arduino reset pin)

Adafruit_SSD1306 display(SCREEN_WIDTH, SCREEN_HEIGHT, &Wire, OLED_RESET);

int ledPin = 25;

int loop_count = 0;

void logoshow(int count)
{
    display.clearDisplay();

    display.setTextSize(1);              // Normal 1:1 pixel scale
    display.setTextColor(SSD1306_WHITE); // Draw white text
    display.setCursor(0, 0);             // Start at top-left corner
    display.println(F("MaPie RP2040 OLED"));
    display.setCursor(0, 20); // Start at top-left corner
    display.print(F("TEST DEMO #"));
    display.println(count);
    display.println(F(""));
    display.println(F("Hello, Makerfabs!"));
    display.display();
    //delay(1000);
}

void setup()
{
    // declare pin to be an output:
  pinMode(ledPin, OUTPUT);
  //Wire.begin(I2C_SDA_PIN,I2C_SCL_PIN);
  //Wire.Wire(I2C_SDA_PIN,I2C_SCL_PIN);
  
  Wire.begin();
  //MbedI2C.setClock(100000UL);
  Wire.setClock(100000UL);
  Serial.begin(115200);
  Serial.println("nI2C Scanner 100Khz");
/**  
  byte error, address;
  int nDevices;
  Serial.println("Scanning...");
  delay(1000);
  nDevices = 0;
  for(address = 1; address < 127; address++ )
  {
    Wire.beginTransmission(address);
    delay(100);
    error = Wire.endTransmission();
    if (error == 0)
    {
      Serial.print("I2C device found at address 0x");
      if (address<16)
        Serial.print("0");
      Serial.print(address,HEX);
      Serial.println("  !");
      nDevices++;
      delay(1000);
    }
    else if (error==4)
    {
      Serial.print("Unknow error at address 0x");
      if (address<16)
        Serial.print("0");
      Serial.println(address,HEX);
    }
  }
  if (nDevices == 0)
    Serial.println("No I2C devices founded");
  else
    Serial.println("done!");
  delay(5000);           // wait 5 seconds for next scan
**/
  // SSD1306_SWITCHCAPVCC = generate display voltage from 3.3V internally
  if (!display.begin(SSD1306_SWITCHCAPVCC, 0x3C))
  { // Address 0x3C for 128x32
      Serial.println(F("SSD1306 allocation failed"));
      for (;;)
        ; // Don't proceed, loop forever
  }
  Serial.println("SSD1306 found");

  display.clearDisplay();

  for(int16_t x=0; x<display.width(); x+=1) //SCREEN_WIDTH
  {
    // The INVERSE color is used so rectangles alternate white/black
    //display.fillRect(i, i, display.width()-i*2, display.height()-i*2, SSD1306_INVERSE);
    //display.fillRect(i, i, display.width(), display.height(), SSD1306_INVERSE);
    for(int16_t y=0; y<display.height(); y+=1) //  
    {
      display.drawPixel(x, y, SSD1306_WHITE);
      //display.display(); // Update screen with each newly-drawn rectangle
    }
    delay(1);
  }
  display.display();
  delay(2000);
  display.clearDisplay();  
  display.setTextColor(SSD1306_WHITE);
  display.setTextSize(1); // Draw 2X-scale text
  display.setCursor(2, 0);
  display.println("MaPie RP2040");
  display.println("0.96\" OLED");
  display.display();

}
void loop()
{
  Serial.print("Serial #");
  Serial.println(loop_count);
  loop_count++;
  logoshow(loop_count);
  digitalWrite(ledPin, (loop_count%2));

  delay(1000);

}

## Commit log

2022-06-16 Add MaPIE lora hardware
    [MaPIE LoRa Radio v2.1.brd, MaPIE LoRa Radio v2.1.sch]
2022-11-29 hardware
    v1.1
    [MaPIE RP2040 0.96‘‘ OLED V1.1.brd, MaPIE RP2040 0.96‘‘ OLED V1.1.sch]

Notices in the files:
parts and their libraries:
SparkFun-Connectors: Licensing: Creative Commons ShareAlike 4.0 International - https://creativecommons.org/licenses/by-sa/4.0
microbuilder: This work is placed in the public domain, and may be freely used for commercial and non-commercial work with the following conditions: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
